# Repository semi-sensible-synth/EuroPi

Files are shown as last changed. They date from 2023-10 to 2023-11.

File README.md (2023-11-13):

# EuroPi (Semi-Sensible Synth THT KiCad remix)

This is a remix of the [original EuroPi](https://github.com/Allen-Synthesis/EuroPi) eurorack module with a few changes:

- Input jacks at bottom, above output jacks
- Uses cheaper (?) tactile buttons
- Uses a 38mm OLED, commonly sold on AliExpress

If you are building one right now ... [use the iBOM](https://rawcdn.githack.com/semi-sensible-synth/EuroPi/e1486020547788293de8dd8d0f69c1b8743ea925/hardware/EuroPi/kicad/ibom/ibom.html) to help with parts placement.

The EuroPi is a fully user reprogrammable module based on the [Raspberry Pi Pico](https://www.raspberrypi.com/products/raspberry-pi-pico/), which allows users to process inputs and controls to produce outputs based on code written in Python. The entire project is open-source.

<p>
  <a href="https://discord.gg/JaQwtCnBV5">
        chat on Discord
  </a>
  <a href="https://www.reddit.com/r/EuroPi/">
        
  </a>
  <a href="https://github.com/Allen-Synthesis/EuroPi/tree/main/software/contrib">
        
  </a>
  <a href="https://github.com/Allen-Synthesis/EuroPi/releases/">
        
  </a>
  
</p>

---

This repository relates to the EuroPi module, however some users may be expecting to see what is now referred to as the 'EuroPi Prototype'. The repository for this (now deprecated) module [can be found here](https://github.com/roryjamesallen/EuroPi-Prototype)

You can find more about this and other projects of mine on [my website](https://www.allensynthesis.co.uk)

europi-sss-tht_module_pron

## Capabilities

* 6 0-10V Control Voltage outputs, each with indicator LED
* 2 Knobs with 12 bit resolution
* 2 Push Buttons
* 1 0-12V Control Voltage input with 12 bit resolution
* 1 Digital input for external clocking or gate sources
* 128x32 OLED Display
* I²C expansion header on the rear for extra sensors or outputs

### Documentation

**Hardware**: Details of the hardware can be found at [hardware README](hardware/EuroPi/README.md). Additionally the [BoM](hardware/EuroPi/bill_of_materials.md) and the [build guide](hardware/EuroPi/build_guide.md) can be found in the hardware folder.

**Software**: Before using any of the software, follow the instructions in [programming_instructions.md](software/programming_instructions.md) to set up and calibrate your module.

A list of user contributed scripts and their usage can be found in [contrib/README.md](software/contrib/README.md).
There is also a [YouTube playlist](https://www.youtube.com/playlist?list=PLbingtr9KGPUdIODLWgzgAdIyN497YyEs) showcasing EuroPi and some of the different scripts available.

The EuroPi firmware API documentation can be found at https://allen-synthesis.github.io/EuroPi/. This documentation will explain all of the available features of the EuroPi firmware API. It also includes some examples of how to use various features of the firmware as well as [interesting_things.md](software/interesting_things.md).

If you would like to extend any of the features of the EuroPi software, you can view the firmware source code at [europi.py](software/firmware/europi.py).

### Issues
If you find any bugs, either in the software, the hardware, or the documentation, please create an Issue by clicking the 'Issue' tab along the top.  
Please feel free to create any issue you see fit, I'll either attempt to fix it or explain it.  
There are Issue templates available, so please choose whichever is most relevant, depending on if your Issue is a hardware or software bug, if it's a documentation error or suggestion, if it's a question about the project as a whole, or a suggestion about the project as a whole.

### License

This module, and any documentation included in this repository, is entirely "free" software and hardware, under different licenses depending on the software, hardware, and documentation itself.

* Software: [Apache 2.0](software/LICENSE)
* Hardware: [CERN OHL-S v2](hardware/LICENSE)
* Documentation: [CC0 1.0](LICENSE)

Anyone is welcome to design their own versions of the idea, or modify my designs.
The only thing I would ask is that you refrain from using the brand name 'Allen Synthesis' on your DIY builds if they have modified my files in any way, just to prevent any confusion if they end up being re-sold or distributed. This is in line with section 8.2 of the CERN license. You may use the brand name if you have simply copied the files from this repository to replicate without modification.
  
If you have a bug fix or improvement that you think is worth sharing, then feel free to send over any pictures or documentation and it can be merged with the main project!
 
### Disclaimer
 
Recreate any of the files found in this repository at your own risk; I will attempt to solve any issues that you might have with my designs, but I can't guarantee that there are not minor bugs in any of the documents, both hardware and software.

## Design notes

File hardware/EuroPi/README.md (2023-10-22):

# EuroPi hardware (Semi-Sensible Synth THT KiCad remix)

This version of EuroPi is a remix with some small changes.

## Differences / changes from stock EuroPi

- Input jacks at bottom, above output jacks
- Uses 14mm high, 6x6mm base tactile buttons with ~6.1-6.2mm diameter plastic caps.
- Uses a 38mm OLED, commonly sold on AliExpress (mounted slightly offset from centre for your OCD)
- Has a bodge zone with some extra holes and exposed pads for cutting traces and re-routing the OLED pins if yours doesn’t follow the ‘CPC’-style pinout (less elegant than the original EuroPi rerouting holes, but intended as a last resort if you happen to have another OLED that still fits)
- Has optional non-electrical pin header to help support the other end of the OLED
- No standoff screw joining boards, extra pin headers at bottom instead
- General re-routing and component position tweaks to make it all work.

## BOM variations of note

- 0.91” OLED (38mm wide, GND/VCC/SCL/SDA): [Ali Express](https://www.aliexpress.com/item/32672229793.html)
- 6x6x14 mm tactile buttons: [Ali Express](https://www.aliexpress.com/item/32960657626.html)
- Tactile button caps: [Ali Express (white)](https://www.aliexpress.com/item/32872180785.html), [Ali Express (black)](https://www.aliexpress.com/item/32873394381.html)

These are common parts across various sellers, so should be relatively easy to find at a good price.

## v0.10.0-sss-tht TODO notes

I have ordered and built a module using the `v0.10.0-sss-tht` production files and it works.
These are some minor changes I would make in a revision.

- Add more component value labels to silkscreen, especially to resistors
- Add + to LED silkscreen
- LED panel holes could be a little smaller (~0.4mm diameter smaller)
- Consider adding pin headers between the front panel and PCB, above the OLED to better secure when using nut-less trimmer pots.
  - _(This would be a female header above the OLED and an SMD right angle male header on exposed pads on the back of the front panel - or get fancy with a solderable standoff like https://www.adafruit.com/product/4207)_
- Build guide: 
  - Solder the I2C header before Pico & power header (tricky otherwise)
  - Solder the bottom centre jack (J5) before bottom board joiner on the opposite side of the board (if using 8x1 with two middle pins removed as joiner). If you forget, it can be soldered from the opposite side of the board.
  - I had to glue my button caps on to the tactile buttons - not a big deal, but I expected them to attach via friction
  - I used small plastic trimmer pots in my first build, however it’s better to use proper metal pots with nuts. This is because without pot nuts, pressing the buttons too hard flexes the PCB away from the front panel. Using [trimmer knobs](https://www.aliexpress.com/item/1005002336855641.html) also help.

# Hardware Specifications

## Outputs
- 1k Output Impedance
- RC filter smoothed PWM
- ~1.5kHz Maximum usable frequency (without changing RC values)
- 0.000176V Maximum ripple peak-to-peak
- 0.0108s Settle time from 0% to 90% duty cycle
- 0-10V

## Analogue Input
- 100k Input Impedance
- 0-12V Readable Range
- Protected for ±36V (TL074 limits, MCP6002 will always clip to ±3.3V)

## Digital Input
- 100k Input Impedance
- 0.8V threshold to read as high

## OLED
- SSD1306 0.91"
- 128 x 32 pixels
- I2C Protocol

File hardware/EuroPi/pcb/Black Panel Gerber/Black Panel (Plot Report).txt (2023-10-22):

Plot Report
-----------

Report Written:     Saturday, December 25, 2021
Design Path:        C:\Users\Rory\Documents\Allen Synthesis Website\Modules\EuroPi\HUGE 8HP, Screen\Hardware\PCB\Alternate Panels\Black Panel.pcb
Design Title:       
Created:            15/10/2021 18:21:02
Last Saved:         25/12/2021 14:56:07
Editing Time:       781 min
Units:              mm (precision 1)

Device Settings
===============

Gerber Settings
===============

    Leading zero suppression.
    G01 assumed throughout.
    Line termination <*> <CR> <LF>.
    3.5 format absolute mm.

    Format commands defined in Gerber file.
    Aperture table defined in Gerber file.
    Hardware arcs allowed.

Drill Settings
==============

    Excellon Format 1
    Format 3.5 absolute in mm.
    Zero suppression None

Plots Output
============

    Plot Job: "C:\Users\Rory\Documents\Allen Synthesis Website\Modules\EuroPi\HUGE 8HP, Screen\Hardware\PCB\Alternate Panels\Black Panel.mop"

Gerber Output
=============

C:\Users\Rory\Documents\Allen Synthesis Website\Modules\EuroPi\HUGE 8HP, Screen\Hardware\PCB\Alternate Panels\Black Panel Gerber\Black Panel - Bottom Silkscreen.gbr

    Layers:
    ---------------------
    Bottom Silkscreen

    D-Code Shape  (mm)
    ---------------------
    D87    Round 0.025

Gerber Output
=============

C:\Users\Rory\Documents\Allen Synthesis Website\Modules\EuroPi\HUGE 8HP, Screen\Hardware\PCB\Alternate Panels\Black Panel Gerber\Black Panel - Bottom Copper.gbr

    Layers:
    -----------------
    Bottom Copper

    D-Code Shape  (mm)
    ----------------------
    D87    Round 0.025
    D93    Round 8.000
    D140   Round 7.000
    D141   Round 10.000
    D142   Round 4.000

Gerber Output
=============

C:\Users\Rory\Documents\Allen Synthesis Website\Modules\EuroPi\HUGE 8HP, Screen\Hardware\PCB\Alternate Panels\Black Panel Gerber\Black Panel - Bottom Copper (Resist).gbr

    Layers:
    -----------------
    Bottom Copper

    D-Code Shape  (mm)
    ----------------------
    D87    Round 0.025
    D93    Round 8.000
    D140   Round 7.000
    D141   Round 10.000
    D142   Round 4.000

Gerber Output
=============

C:\Users\Rory\Documents\Allen Synthesis Website\Modules\EuroPi\HUGE 8HP, Screen\Hardware\PCB\Alternate Panels\Black Panel Gerber\Black Panel - Bottom Copper (Paste).gbr

    Layers:
    -----------------
    Bottom Copper

    D-Code Shape  (mm)
    ---------------------

NC Drill Output
===============

C:\Users\Rory\Documents\Allen Synthesis Website\Modules\EuroPi\HUGE 8HP, Screen\Hardware\PCB\Alternate Panels\Black Panel Gerber\Black Panel - Drill Data - [Through Hole].drl

    Output:
    ---------------------------
    Plated Round Drill Holes
    Plated Slots

    Tool  Size       Count   ID
    ----------------------------------
    T001  3.10000 mm 6     I
    T002  3.20000 mm 2     H
    T003  6.10000 mm 8     F
    T004  7.10000 mm 2     K
    T005  9.10000 mm 2     G
    ----------------------------------
    Total            20
    ----------------------------------

C:\Users\Rory\Documents\Allen Synthesis Website\Modules\EuroPi\HUGE 8HP, Screen\Hardware\PCB\Alternate Panels\Black Panel Gerber\Black Panel - Drill Data - [Through Hole] (Unplated).drl

    Output:
    -----------------------------
    Unplated Round Drill Holes
    Unplated Slots

    Tool  Size Count   ID
    ----------------------------
    ----------------------------
    Total      0
    ----------------------------

Gerber Output
=============

C:\Users\Rory\Documents\Allen Synthesis Website\Modules\EuroPi\HUGE 8HP, Screen\Hardware\PCB\Alternate Panels\Black Panel Gerber\Black Panel - Outline.gbr

    Layers:
    ------------------
    Board Outlines

    D-Code Shape  (mm)
    ---------------------
    D13    Round 0.305

End Of Report.

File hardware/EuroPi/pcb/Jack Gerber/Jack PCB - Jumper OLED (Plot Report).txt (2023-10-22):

Plot Report
-----------

Report Written:     Monday, December 20, 2021
Design Path:        C:\Users\Rory\Documents\Allen Synthesis Website\Modules\EuroPi\HUGE 8HP, Screen\Hardware\PCB\Jack PCB - Jumper OLED.pcb
Design Title:       
Created:            09/09/2021 13:46:40
Last Saved:         20/12/2021 13:36:13
Editing Time:       1605 min
Units:              mm (precision 1)

Device Settings
===============

Gerber Settings
===============

    Leading zero suppression.
    G01 assumed throughout.
    Line termination <*> <CR> <LF>.
    3.5 format absolute mm.

    Format commands defined in Gerber file.
    Aperture table defined in Gerber file.
    Hardware arcs allowed.

Drill Settings
==============

    Excellon Format 1
    Format 3.5 absolute in mm.
    Zero suppression None

Plots Output
============

    Plot Job: "C:\Users\Rory\Documents\Allen Synthesis Website\Modules\EuroPi\HUGE 8HP, Screen\Hardware\PCB\Jack PCB - Jumper OLED.mop"

Gerber Output
=============

C:\Users\Rory\Documents\Allen Synthesis Website\Modules\EuroPi\HUGE 8HP, Screen\Hardware\PCB\Jack Gerber\Jack PCB - Jumper OLED - Top Copper.gbr

    Layers:
    --------------
    Top Copper

    D-Code Shape  (mm)
    ----------------------
    D13    Round 0.305
    D14    Round 0.254
    D15    Round 0.500
    D17    Round 1.600
    D18    Round 1.524
    D19    Round 2.000
    D29    Round 2.500
    D72    Square 2.500
    D73    Round 3.500
    D75    Round 1.500
    D129   Round 3.200
    D137   Round 1.800

Gerber Output
=============

C:\Users\Rory\Documents\Allen Synthesis Website\Modules\EuroPi\HUGE 8HP, Screen\Hardware\PCB\Jack Gerber\Jack PCB - Jumper OLED - Top Copper (Resist).gbr

    Layers:
    --------------
    Top Copper

    D-Code Shape  (mm)
    ----------------------
    D71    Round 1.778
    D20    Round 2.254
    D77    Round 2.754
    D78    Square 2.754
    D79    Round 3.754
    D81    Round 1.754
    D130   Round 3.454
    D138   Round 2.054

Gerber Output
=============

C:\Users\Rory\Documents\Allen Synthesis Website\Modules\EuroPi\HUGE 8HP, Screen\Hardware\PCB\Jack Gerber\Jack PCB - Jumper OLED - Top Copper (Paste).gbr

    Layers:
    --------------
    Top Copper

    D-Code Shape  (mm)
    ---------------------

Gerber Output
=============

C:\Users\Rory\Documents\Allen Synthesis Website\Modules\EuroPi\HUGE 8HP, Screen\Hardware\PCB\Jack Gerber\Jack PCB - Jumper OLED - Top Silkscreen.gbr

    Layers:
    ------------------
    Top Silkscreen

    D-Code Shape  (mm)
    ---------------------
    D10    Round 0.127
    D13    Round 0.305
    D137   Round 1.800
    D139   Round 0.150

Gerber Output
=============

C:\Users\Rory\Documents\Allen Synthesis Website\Modules\EuroPi\HUGE 8HP, Screen\Hardware\PCB\Jack Gerber\Jack PCB - Jumper OLED - Bottom Copper.gbr

    Layers:
    -----------------
    Bottom Copper

    D-Code Shape  (mm)
    ---------------------
    D15    Round 0.500
    D17    Round 1.600
    D18    Round 1.524
    D19    Round 2.000
    D129   Round 3.200
    D137   Round 1.800

Gerber Output
=============

C:\Users\Rory\Documents\Allen Synthesis Website\Modules\EuroPi\HUGE 8HP, Screen\Hardware\PCB\Jack Gerber\Jack PCB - Jumper OLED - Bottom Copper (Resist).gbr

    Layers:
    -----------------
    Bottom Copper

    D-Code Shape  (mm)
    ---------------------
    D71    Round 1.778
    D20    Round 2.254
    D130   Round 3.454
    D138   Round 2.054

Gerber Output
=============

C:\Users\Rory\Documents\Allen Synthesis Website\Modules\EuroPi\HUGE 8HP, Screen\Hardware\PCB\Jack Gerber\Jack PCB - Jumper OLED - Bottom Copper (Paste).gbr

    Layers:
    -----------------
    Bottom Copper

    D-Code Shape  (mm)
    ---------------------

Gerber Output
=============

C:\Users\Rory\Documents\Allen Synthesis Website\Modules\EuroPi\HUGE 8HP, Screen\Hardware\PCB\Jack Gerber\Jack PCB - Jumper OLED - Bottom Silkscreen.gbr

    Layers:
    ---------------------
    Bottom Silkscreen

    D-Code Shape  (mm)
    ---------------------
    D10    Round 0.127
    D11    Round 0.100
    D13    Round 0.305

NC Drill Output
===============

C:\Users\Rory\Documents\Allen Synthesis Website\Modules\EuroPi\HUGE 8HP, Screen\Hardware\PCB\Jack Gerber\Jack PCB - Jumper OLED - Drill Data - [Through Hole].drl

    Output:
    ---------------------------
    Plated Round Drill Holes
    Plated Slots

    Tool  Size       Count   ID
    ----------------------------------
    T001  0.60000 mm 12    M
    T002  0.80000 mm 57    W
    T003  0.88900 mm 4     O
    T004  1.00000 mm 56    A
    T005  1.10000 mm 14    C
    T006  1.50000 mm 24    R
    T007  3.00000 mm 5     D
    ----------------------------------
    Total            172
    ----------------------------------

C:\Users\Rory\Documents\Allen Synthesis Website\Modules\EuroPi\HUGE 8HP, Screen\Hardware\PCB\Jack Gerber\Jack PCB - Jumper OLED - Drill Data - [Through Hole] (Unplated).drl

    Output:
    -----------------------------
    Unplated Round Drill Holes
    Unplated Slots

    Tool  Size Count   ID
    ----------------------------
    ----------------------------
    Total      0
    ----------------------------

Gerber Output
=============

C:\Users\Rory\Documents\Allen Synthesis Website\Modules\EuroPi\HUGE 8HP, Screen\Hardware\PCB\Jack Gerber\Jack PCB - Jumper OLED - Drill Ident Drawing - [Through Hole].gbr

    Layers:
    ------------------
    [Through Hole]

Drill Ident Drawing
===================

    Drill Plated Size  Shape ID
    ------------------------------------
    1.000 Y      2.540 Round A
    1.100 Y      2.540 Round C
    3.000 Y      2.540 Round D
    0.600 Y      2.540 Round M
    0.889 Y      2.540 Round O
    1.500 Y      2.540 Round R
    0.800 Y      2.540 Round W

    D-Code Shape  (mm)
    ---------------------
    D10    Round 0.127
    D12    Round 2.540

Gerber Output
=============

C:\Users\Rory\Documents\Allen Synthesis Website\Modules\EuroPi\HUGE 8HP, Screen\Hardware\PCB\Jack Gerber\Jack PCB - Jumper OLED - Outline.gbr

    Layers:
    ------------------
    Board Outlines

    D-Code Shape  (mm)
    ---------------------
    D13    Round 0.305

End Of Report.

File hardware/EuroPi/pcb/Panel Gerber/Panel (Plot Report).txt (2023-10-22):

Plot Report
-----------

Report Written:     Thursday, December 16, 2021
Design Path:        C:\Users\Rory\Documents\Allen Synthesis Website\Modules\EuroPi\HUGE 8HP, Screen\Hardware\PCB\Panel.pcb
Design Title:       
Created:            15/10/2021 18:21:02
Last Saved:         16/12/2021 18:22:28
Editing Time:       334 min
Units:              mm (precision 1)

Device Settings
===============

Gerber Settings
===============

    Leading zero suppression.
    G01 assumed throughout.
    Line termination <*> <CR> <LF>.
    3.5 format absolute mm.

    Format commands defined in Gerber file.
    Aperture table defined in Gerber file.
    Hardware arcs allowed.

Drill Settings
==============

    Excellon Format 1
    Format 3.5 absolute in mm.
    Zero suppression None

Plots Output
============

Gerber Output
=============

C:\Users\Rory\Documents\Allen Synthesis Website\Modules\EuroPi\HUGE 8HP, Screen\Hardware\PCB\Panel Gerber\Panel - Top Copper.gbr

    Layers:
    --------------
    Top Copper

    D-Code Shape  (mm)
    ----------------------
    D93    Round 8.000
    D140   Round 7.000
    D141   Round 10.000
    D142   Round 4.000

Gerber Output
=============

C:\Users\Rory\Documents\Allen Synthesis Website\Modules\EuroPi\HUGE 8HP, Screen\Hardware\PCB\Panel Gerber\Panel - Bottom Silkscreen.gbr

    Layers:
    ---------------------
    Bottom Silkscreen

    D-Code Shape  (mm)
    ---------------------
    D87    Round 0.025

Gerber Output
=============

C:\Users\Rory\Documents\Allen Synthesis Website\Modules\EuroPi\HUGE 8HP, Screen\Hardware\PCB\Panel Gerber\Panel - Bottom Copper (Resist).gbr

    Layers:
    -----------------
    Bottom Copper

    D-Code Shape  (mm)
    ---------------------

Gerber Output
=============

C:\Users\Rory\Documents\Allen Synthesis Website\Modules\EuroPi\HUGE 8HP, Screen\Hardware\PCB\Panel Gerber\Panel - Bottom Copper (Paste).gbr

    Layers:
    -----------------
    Bottom Copper

    D-Code Shape  (mm)
    ---------------------

NC Drill Output
===============

C:\Users\Rory\Documents\Allen Synthesis Website\Modules\EuroPi\HUGE 8HP, Screen\Hardware\PCB\Panel Gerber\Panel - Drill Data - [Through Hole].drl

    Output:
    ---------------------------
    Plated Round Drill Holes
    Plated Slots

    Tool  Size       Count   ID
    ----------------------------------
    T001  3.10000 mm 6     I
    T002  3.20000 mm 2     H
    T003  6.10000 mm 8     F
    T004  7.10000 mm 2     K
    T005  9.10000 mm 2     G
    ----------------------------------
    Total            20
    ----------------------------------

C:\Users\Rory\Documents\Allen Synthesis Website\Modules\EuroPi\HUGE 8HP, Screen\Hardware\PCB\Panel Gerber\Panel - Drill Data - [Through Hole] (Unplated).drl

    Output:
    -----------------------------
    Unplated Round Drill Holes
    Unplated Slots

    Tool  Size Count   ID
    ----------------------------
    ----------------------------
    Total      0
    ----------------------------

Gerber Output
=============

C:\Users\Rory\Documents\Allen Synthesis Website\Modules\EuroPi\HUGE 8HP, Screen\Hardware\PCB\Panel Gerber\Panel - Outline.gbr

    Layers:
    ------------------
    Board Outlines

    D-Code Shape  (mm)
    ---------------------
    D13    Round 0.305

End Of Report.

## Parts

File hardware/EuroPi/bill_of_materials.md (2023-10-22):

# Bill of Materials

In addition to the Front Panel, Jack PCB, and Pico PCB (bought from Allen Synthesis or a third-party supplier), you will need the following components to complete your build.
You will also need one 3.5mm cable (normal Eurorack patch cable) to perform the calibration process.  
  
Please note that a few of these are multi-packs of components, and there may well be cheaper alternatives if you are doing a single build, so as long as the specification is the same you can get any of these components from any supplier most accessible to you.

| Component | Quantity | Value | Description | Suggested Supplier
|-|-|-|-|-|
| R1 - R12, R19 - R20 | 14 | 1k | 1 Kiloohm Resistor | [CPC](https://cpc.farnell.com/unbranded/mf25-1k/resistor-0-25w-1-1k/dp/RE03722)
|R13 - R18 | 6 | 4.7k | 4.7 Kiloohm Resistor | [CPC](https://cpc.farnell.com/unbranded/mf25-4k7/resistor-0-25w-1-4k7/dp/RE03757)
| R21 - R23 | 3 | 22k | 22 Kiloohm Resistor | [CPC](https://cpc.farnell.com/unbranded/mf25-22k/resistor-0-25w-1-22k/dp/RE03743)
| R24 - R26 | 3 | 10k | 10 Kiloohm Resistor | [CPC](https://cpc.farnell.com/unbranded/mf25-10k/resistor-0-25w-1-10k/dp/RE03723)
| R27 - R34 | 8 | 100k | 100 Kiloohm Resistor | [CPC](https://cpc.farnell.com/unbranded/mf25-100k/resistor-0-25w-1-100k/dp/RE03724)
| R35 - R40 | 6 | 220k | 220 Kiloohm Resistor | [CPC](https://cpc.farnell.com/unbranded/mf25-220k/resistor-0-25w-1-220k/dp/RE03744)
| C1 - C2 | 2 | 1uF | 1 Microfarad Capacitor (Polarised)| [CPC](https://cpc.farnell.com/multicomp/mcmhr50v105m4x7/capacitor-1uf-50v-radial-105-deg/dp/CA08237)
| C3 - C14 | 12 | 100nF | 100 Nanofarad Capacitor (Non-Polarised)| [CPC](https://cpc.farnell.com/multicomp/mcrr50104x7rk0050/capacitor-100nf-50v/dp/CA06296)
| C15 - C16 | 2 | 10uF | 10 Microfarad Capacitor (Polarised)| [CPC](https://cpc.farnell.com/panasonic/eeueb1j100s/capacitor-10uf-63v-5x11mm/dp/CA08350)
| D1 - D4 | 4 | 1N5817 | Schottky Diode | [CPC](https://cpc.farnell.com/multicomp-pro/1n5817/schottky-rectifier-1a-20v-do-204al/dp/SC15528)
| LED1 - LED6 | 6 | L-424HDT | 3mm LED | [CPC](https://cpc.farnell.com/kingbright/l-424hdt/led-flat-top-3mm-red/dp/SC11541)
| VR1 - VR2 | 2 | 10k | 10 Kiloohm Linear Rotary Potentiometer | [CPC](https://cpc.farnell.com/alps/rk09k11310kb/potentiometer-10k-lin/dp/RE04560), [Thonk](https://www.thonk.co.uk/shop/alpha-9mm-pots-vertical-t18/) (B10K - T18 Shaft - Alpha Vertical Potentiometer)
| SW1 - SW2 | 2 | 6x6 tactile button | 6x6 14mm high momentary tactile button | [Ali Express](https://www.aliexpress.com/item/32960657626.html)
| | 2 | G63 6mm button cap | Tactile button cap | [Ali Express (white)](https://www.aliexpress.com/item/32872180785.html), [Ali Express (black)](https://www.aliexpress.com/item/32873394381.html)
| OLED1 | 1 | 0.91" SSD1306 | I2C OLED Display (38 mm wide) | [Ali Express](https://www.aliexpress.com/item/32672229793.html)
| J1 - J8 | 8 | PJ398SM | Thonkiconn 3.5mm Mono Jack | [Thonk](https://www.thonk.co.uk/shop/thonkiconn/), [Banananuts](https://www.thonk.co.uk/shop/bananuts/), [Cosmonuts](https://www.thonk.co.uk/shop/cosmonuts/)
| CONN0 | 2 (pairs) | 20x1 2.54mm | Pico Connection Header (Male + Female) | [Male](https://cpc.farnell.com/harwin/m22-2012005/header-vertical-1row-20way/dp/CN14644), [Female](https://cpc.farnell.com/multicomp/2212s-20sg-85/socket-pcb-1-row-20way/dp/CN14539)
| CONN1 - CONN4 | 2 (pairs) | 4x2 2.54mm | PCB Connection Header (Male + Female) | [Male](https://cpc.farnell.com/harwin/m20-9980445/header-2row-4way/dp/CN14381), [Female](https://cpc.farnell.com/multicomp/2214s-08sg-85/socket-pcb-2-54mm-2-row-vert-8way/dp/CN18449)
| CONN5 | 1 | 4x1 2.54mm | I2C Header (Male) | [CPC](https://cpc.farnell.com/multicomp/2211s-04g/header-1-row-vert-4way/dp/CN14489)
| CONN6 | 1 | 5x2 2.54mm | Eurorack Power Header (Shrouded) | [CPC](https://cpc.farnell.com/3m/n2510-6002rb/2-54mm-header-straight-10-way/dp/CN20355)
| TL074-1 - TL074-2 | 2 | TL074 DIP | Quad Operational Amplifier (+ Socket) | [Op-Amp](https://cpc.farnell.com/texas-instruments/tl074acn/ic-op-amp-quad-jfet-dip14/dp/SC16602), [Socket](https://cpc.farnell.com/unbranded/mc-2227-14-03-f1/socket-ic-dil-0-3-tube-34-14way/dp/SC08125)
| MCP6002 | 1 | MCP6002 DIP | Dual Operational Amplifier (+ Socket) | [Op-Amp](https://cpc.farnell.com/microchip/mcp6002-i-p/ic-op-amp-1-8v-1mhz-dual-pdip8/dp/SC17118), [Socket](https://cpc.farnell.com/multicomp/spc15494/dip-socket-8pos-2row-2-54mm-th/dp/SC15358)
| Q1 | 1 | 2N3904 | NPN Transistor | [CPC](https://cpc.farnell.com/multicomp-pro/2n3904/transistor-npn-to-92/dp/SC15978)
| 7805 | 1 | L7805ABV | 5V Linear Voltage Regulator | [CPC](https://cpc.farnell.com/stmicroelectronics/l7805abv/ic-v-reg-5v/dp/SC10586)
| | 1 | 11mm | M2.5 PCB Standoff + 2 Screws | [Standoff](https://cpc.farnell.com/ettinger/05-02-113/spacer-hex-m2-5-11mm-length-brass/dp/PC01763), [Screws](https://cpc.farnell.com/unbranded/pp2m5-6/screw-pan-pozi-m2-5-x-6mm-100pk/dp/FN02140)
| | 2 | T18 Shaft | Knobs | [Thonk](https://www.thonk.co.uk/shop/1900h-t18/) NOTE: If you buy D-Shaft potentiometers, the knobs must be 'Reverse-D-Shaft' type.
| | 1 | 10 - 16 Pin | Eurorack Power Cable | [Thonk](https://www.thonk.co.uk/shop/eurorack-power-cables/)
| | 1 | | Micro USB Cable (Capable of Data Transfer) | [CPC](https://cpc.farnell.com/pro-signal/psg91562/lead-usb-a-male-micro-b-male-black/dp/CS32732), [The Pi Hut](https://thepihut.com/products/usb-to-micro-usb-cable-0-5m)
| | 1 | | Raspberry Pi Pico | [The Pi Hut](https://thepihut.com/products/raspberry-pi-pico), [CPC](https://cpc.farnell.com/raspberry-pi/raspberry-pi-pico/raspberry-pi-pico-rp2040-mcu-board/dp/SC17106)

#### Note about OLED

The OLED is a different model to the original EuroPi design. This version expects 38mm wide 0.91" OLEDs (common on Ali Express), albeit slightly offset from center. The default pin configuration is correct for the OLED in the BOM (GND/VCC/SCL/SDA), however the module supports alternative pin configurations via a some exposed pads in 'bodge' area. You can connect these as required if you happen to have a different pinout. 

38mm_OLED_dimensions

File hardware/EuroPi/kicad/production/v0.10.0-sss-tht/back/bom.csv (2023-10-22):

Designator | Footprint | Quantity | Value | LCSC Part #
C1, C2 | CP_Radial_D5.0mm_P2.50mm | 2 | 1uF
C10, C11, C12, C13, C14, C3, C4, C5, C6, C9 | Capacitor Small Non-Polarised | 10 | 100nF
C15, C16 | CP_Radial_D8.0mm_P3.80mm | 2 | 10uF
CONN1, CONN3 | PinHeader_2x04_P2.54mm_Vertical | 2 | Conn_02x04_Counter_Clockwise_M
CONN5 | PinHeader_1x04_P2.54mm_Vertical | 1 | Conn_01x04_Male
CONN6, CONN7 | PinHeader_1x03_P2.54mm_Vertical | 2 | Conn_02x03_M
D1, D2, D3, D4 | Schottky Diode | 4 | type="D" model="DIODE" lib=""
EuroPower1 | Eurorack Power Header Unlabeled | 1 | Eurorack Power
IC1, IC2 | DIP-14 IC Socket | 2 | TL074
IC3 | DIP-8 IC Socket | 1 | MCP6002
Q1 | TO-92 | 1 | 2N2222
R1, R2, R3, R4, R5, R6 | R_Axial_DIN0204_L3.6mm_D1.6mm_P7.62mm_Horizontal | 6 | 1K
R21, R22, R23 | R_Axial_DIN0204_L3.6mm_D1.6mm_P7.62mm_Horizontal | 3 | 22K
R24, R25, R26 | R_Axial_DIN0204_L3.6mm_D1.6mm_P7.62mm_Horizontal | 3 | 10K
R27, R28, R29, R30, R31, R32, R33, R34 | R_Axial_DIN0204_L3.6mm_D1.6mm_P7.62mm_Horizontal | 8 | 100K
R35, R36, R37, R38, R39, R40 | R_Axial_DIN0204_L3.6mm_D1.6mm_P7.62mm_Horizontal | 6 | 220K
REG1 | TO-220-3_Vertical | 1 | L7805
RPI1 | Raspberry Pi Pico | 1 | Raspberry_Pi_Pico

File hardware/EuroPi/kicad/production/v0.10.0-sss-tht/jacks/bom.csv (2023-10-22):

Designator | Footprint | Quantity | Value | LCSC Part #
C7, C8 | Capacitor Small Non-Polarised | 2 | 100nF
CONN10, CONN8, CONN9 | PinSocket_1x03_P2.54mm_Vertical | 3 | Conn_02x03_F
CONN11 | PinHeader_1x04_P2.54mm_Vertical | 1 | Conn_01x04_Counter_Clockwise_M
CONN2, CONN4 | PinSocket_2x04_P2.54mm_Vertical | 2 | Conn_02x04_Counter_Clockwise_F
J1, J2, J3, J4, J5, J6, J7, J8 | Thonkiconn Mono Jack | 8 | Thonkiconn_Mono_Jack
JP1, JP2, JP3, JP4 | SolderJumper-2_P1.3mm_Bridged_Pad1.0x1.5mm | 4 | SolderJumper_2_Bridged
LED1, LED2, LED3, LED4, LED5, LED6 | LED 3mm | 6 | LED
OLED1 | OLED SSD1306 0.91-38mm | 1 | OLED SSD1306_0.91"
R10, R11, R12, R19, R20, R7, R8, R9 | R_Axial_DIN0204_L3.6mm_D1.6mm_P7.62mm_Horizontal | 8 | 1K
R13, R14, R15, R16, R17, R18 | R_Axial_DIN0204_L3.6mm_D1.6mm_P7.62mm_Horizontal | 6 | 4K7
SW1, SW2 | SW_PUSH_6mm | 2 | SW_Push
VR1 | Potentiometer_RV09 | 1 | KNOB 1
VR2 | Potentiometer_RV09 | 1 | KNOB 2

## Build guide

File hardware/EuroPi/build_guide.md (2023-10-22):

# Build Guide

> **NOTE:** _This build guide hasn't been updated for the "Semi-Sensible Synth THT KiCad remix" version, however most parts are very similar. Follow the [iBOM](kicad/ibom/ibom.html)_

----

#### Introduction
This document will go through the assembly of the EuroPi module.  
If you have bought only a Panel + PCB kit, you will need to also buy all of the components found in the [bill of materials](/hardware/EuroPi/bill_of_materials.md).  
  
This build is entirely through-hole (not even any pre-soldered SMD components!) so don't worry if you're fairly new to DIY, these instructions should be all you need to make your module.  
  
This guide should explain every step in enough detail, but there are some things left out for simplicity's sake, such as the fact that after each step any long legs will need to be snipped using your wire snips or scissors. This is only necessary for components with long legs, so resistors, capacitors, and LEDs. You don't need to snip anything off any of the headers, the 7805, the jacks, potentiometers, or IC sockets.  
 
#### Skiff Friendly Build 
There are two options for some of the build, one of which makes the module more skiff friendly (37mm deep as opposed to 45mm). If you wish to make the thinner version, simply click the links that say [Skiff Friendly Option](), and follow the instructions to guide you back into the normal build at the right points. Simply ignore these links if you don't mind the module being slightly deeper.

1 all
  
## Required tools
- Soldering Iron + Solder
- Wire Snips / Scissors
- Multimeter (Very nice to have but non-essential)

2 tools

## Preparation

#### If not already soldered, solder the headers to the Pico so that they are on the opposite side to the black integrated chips. It may help to push it into a breadboard to make sure the headers are straight
_DSC2386

## Pico PCB

The 'Pico PCB' is the PCB with the outline of the Pico on it.  
The 'front' of the Pico PCB is the side with the actual Raspberry Pi Pico on it, and the 'back' is the side with the transistor outline on it.

|Front|Back|
|-----|----|
|||

#### Required Components for Pico PCB
|Component|Quantity|
|---|---|
|1k Resistor|6|
|22k Resistor|3|
|100k Resistor|8|
|220k Resistor|6|
|10k Resistor|3|
|Schottky Diode|4|
|100nF Capacitor|10|
|14 Pin IC Socket|2|
|8 Pin IC Socket|1|
|NPN Transistor|1|
|1uF Capacitor|2|
|4x2 Female Header|2|
|Shrouded Power Header|1|
|4x1 Male Header|1|
|20x1 Female Pico Header|2|
|10uF Capacitor|2|

---

### Resistors

#### Solder the 1k resistors to the front (R1, R2, R3, R4, R5, R6)
_DSC2333
_DSC2335

#### Solder the 22k resistors to the front (R21, R22, R23)
_DSC2338

#### Solder the 100k resistors to the front (R28, R29, R30, R31, R32, R33, R34)
_DSC2339

#### Solder the 220k resistors to the front (R35, R36, R37, R38, R39, R40)
_DSC2340

#### Solder the 10k resistors to the back (R24, R25, R26)
_DSC2341

#### Solder the 100k resistor to the back (R27)
_DSC2342

---

### Diodes

#### Solder the Schottky diodes to the front (D2, D3, D4), taking care of the polarity
_DSC2343

#### Solder the Schottky diode to the back (D1), taking care of the polarity
_DSC2344

---

### Small Capacitors

#### Solder the 100nF capacitors to the front (C3, C4, C5, C6, C9, C10, C11, C12, C13, C14)
_DSC2345

---

### IC Sockets

#### Solder the 14 Pin IC sockets to the front (TL072-1, TL072-2), lining up the notch with the white square on the PCB
_DSC2346

#### Solder the 8 pin IC socket to the front (MCP6002), lining up the notch with the white square on the PCB
_DSC2347

---

### Transistor

#### Solder the NPN transistor to the back (Q1), lining up the flat edge with the line on the PCB
_DSC2348

---

### Medium Capacitors

#### Solder the 1uF capacitors to the front (C1, C2), taking care of the polarity. The white stripe on the capacitor lines up with the stripe on the PCB
_DSC2349

---

### Headers

#### Solder the female headers to the back
_DSC2350

#### Solder the shrouded power header to the front
_DSC2351

#### Solder the I²C header to the front
_DSC2352

[Skiff Friendly Option](skiff_friendly_instructions.md#step-1)

#### Push the female Pico headers onto the Pico itself
_DSC2355

#### Press this new assembly onto the footprint on the PCB
_DSC2356

#### Solder the female headers from the back
_DSC2357

#### Remove the Pico from the female headers
_DSC2358
_DSC2359

---

### Large Capacitors

#### Solder the 10uF capacitors to the front (C15, C16), taking care of the polarity. The white stripe on the capacitor lines up with the stripe on the PCB
_DSC2360

---

### 7805

[Skiff Friendly Option](skiff_friendly_instructions.md#step-2)

#### Solder the 7805 power regulator to the front, with the metal side in line with the white stripe on the PCB
  
_DSC2361

---

## Jack PCB

The 'Jack PCB' is the remaining board, with the outlines for the front panel components.  
The 'front' of the Jack PCB is the side with the OLED, jack, and button outlines, and the 'back' is the side with the OLED configuration diagram.

|Front|Back|
|-----|----|
|||

---

### Resistors

#### Solder the 1k resistors to the back (R7, R8, R9, R10, R11, R12, R19, R20)
_DSC2362 5

---

#### Solder the 4.7k resistors to the back (R13, R14, R15, R16, R17, R18)
_DSC2362

---

### Small Capacitors

#### Solder the 100nF capacitors to the back (C7, C8). If your board has a polarity marking, ignore it unless you are deliberately using larger polarised capacitors than the BOM calls for, in which case make sure they line up with the PCB marking
_DSC2363

---

### Headers

#### Push the male headers into the female headers that you soldered to the Pico PCB
_DSC2364

#### Push the Jack PCB onto the other side of the male headers
_DSC2365

#### Solder the male headers to the Jack PCB
_DSC2366

#### Pull the two PCBs apart carefully to reveal the perfectly aligned male headers on the Jack PCB
_DSC2367

---

#### OLED Configuration
There are two pin configurations that the OLED used in this build commonly comes in, which are labelled on the board 'TPH' (The Pi Hut), and 'CPC' (CPC, AliExpress, most other suppliers).  
The Pi Hut display is preferable as it does not have pre-soldered headers, so is easier to mount on the board. However the CPC display is still entirely usable.  
  
This configuration setup allows you to tell the module which display you are using, as their pins are ordered differently:  
TPH: VCC, GND, SDA, SCL  
CPC: SDA, SCL, VCC, GND
  
Don't ask my why there is still not a standard for I²C pin layout in the year 2021, but here we are, and here is how to tell the module which layout you are using:
  
#### Snip some resistor legs and bend them over the end of something small and round, such as needle-nose pliers
_DSC2410

#### Push the snipped legs into the holes on the PCB according to the diagram and which OLED you have, and then solder either from the top or the bottom
_DSC2411

---

### Front Panel Components

#### Solder the push buttons to the front (SW1, SW2)
_DSC2370

#### Solder the OLED Display to the front
This is quite an awkward operation as the distance the headers need to occupy is not standard to the lengths that 2.54mm headers come in. If you are using a CPC display, your headers are probably pre-soldered, in which case you need to prop the display up somehow while you solder one pin, then go on to solder the rest once you're sure it's straight.
  
If your display is CPC, the pins will be flush with the PCB if it's at the correct height, which is difficult but possible to solder.  
  
If your display is TPH, you can either solder pins and do it the same way as the CPC method, or use extra-long pin headers instead which will make the soldering process easier, as they will protrude far enough to get a better solder joint.

_DSC2375

#### Place the potentiometers (VR1, VR2) onto the front but don't solder yet
_DSC2376

#### Place the jacks (J1, J2, J3, J4, J5, J6, J7, J8) onto the front but don't solder yet
_DSC2377

#### Place the LEDs (LED1, LED2, LED3, LED4, LED5, LED6) onto the front but don't solder yet, lining up the short leg with the white stripe on the PCB
_DSC2378

#### Push the front panel onto the components, lining up the LEDs so they are flush
_DSC2379

#### Place an elastic band or hair bobble around the PCB and panel to hold them together. I used the plastic coated wire that came with my USB cable
_DSC2380

#### Solder all the components from the back. For the potentiometers, only solder the large lugs on the sides if yours are trimmer type potentiometers. Do not solder the lugs if the potentiometers came with nuts.
_DSC2381

---

## Finish off the assembly

#### Screw the PCB standoff onto the Jack PCB so that the standoff is on the back and the screw on the front
_DSC2383

#### Push the two PCBs together, keeping them both straight to avoid bending the header pins
_DSC2384

#### Screw the second screw into the PCB standoff through front of the Pico PCB to hold the two PCBs together firmly
Don't over-tighten so hard that you damage the PCB, but you also don't want this to rattle loose so make sure it is secure.
_DSC2385

#### Push the Pico into its slot on the Pico PCB
_DSC2387

#### If not done already, peel the protective film off the OLED display
_DSC2389

#### Screw all of the nuts on to hold the components to the front panel. 
If your potentiometer came with nuts, use them, otherwise just screw on the jacks.
Also pop on the knobs.
_DSC2390

#### Finally, pop the TL074 and MCP6002 Op-Amps into their respective sockets, making sure the notch in the IC matches the notch on the socket
_DSC2391

---

### (Optional) Multimeter Tests
Use your multimeter set to continuity mode for these tests.

#### Check that there is no continuity between +12V and -12V, between +12V and Ground, and between -12V and Ground on the power header
_DSC2395

If there is continuity on any checks where there shouldn't be then make sure your solder joints are good and that there is no dirt or stray solder bridging any connections. Also make sure that your diodes and power cable are all the correct orientation.

---

### Smoke Test

#### Connect your module to your Eurorack power supply without any other modules connected
_DSC2396

Make sure the cable is connected so that the 'key' on the cable slots into the notch on the header, and the red stripe is on the bottom side of the module.
Turn on your power supply and check for any smoke or discolouration of the PCB around the power connector, and immediately unplug if either occur.  
If all is groovy, the congratulations, you've finished building your EuroPi!

---

## Admire your handiwork!

_DSC2397

#### If you have any issues with the build process or programming that are not covered in the [troubleshooting guide](/troubleshooting.md) then please drop us an email at [contact@allensynthesis.co.uk](mailto:contact@allensynthesis.com)

#### Share photos of your build with us on [Instagram](https://www.instagram.com/allensynthesis/), or [email us](mailto:contact@allensynthesis.com)!

#### Now just follow the [programming instructions](/software/programming_instructions.md) to get ready to use your new EuroPi!

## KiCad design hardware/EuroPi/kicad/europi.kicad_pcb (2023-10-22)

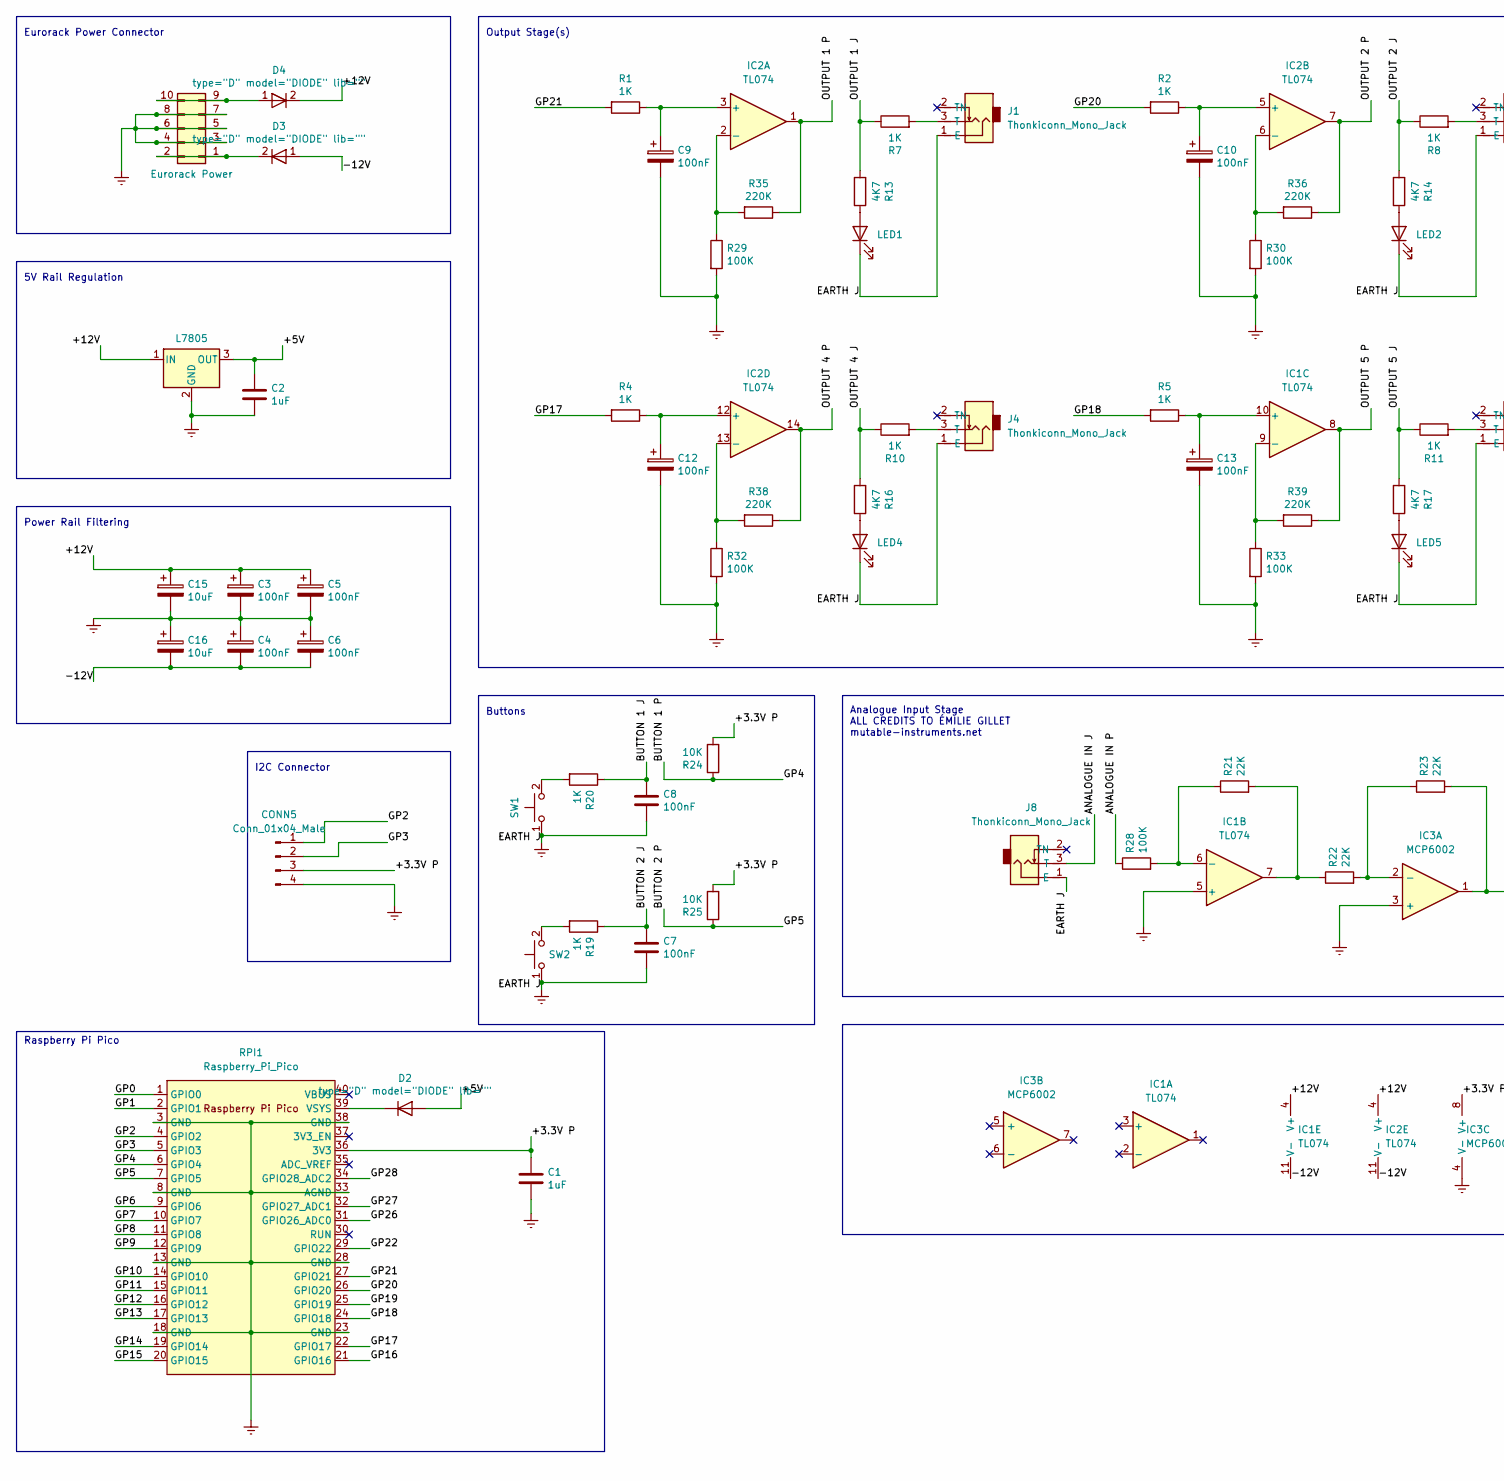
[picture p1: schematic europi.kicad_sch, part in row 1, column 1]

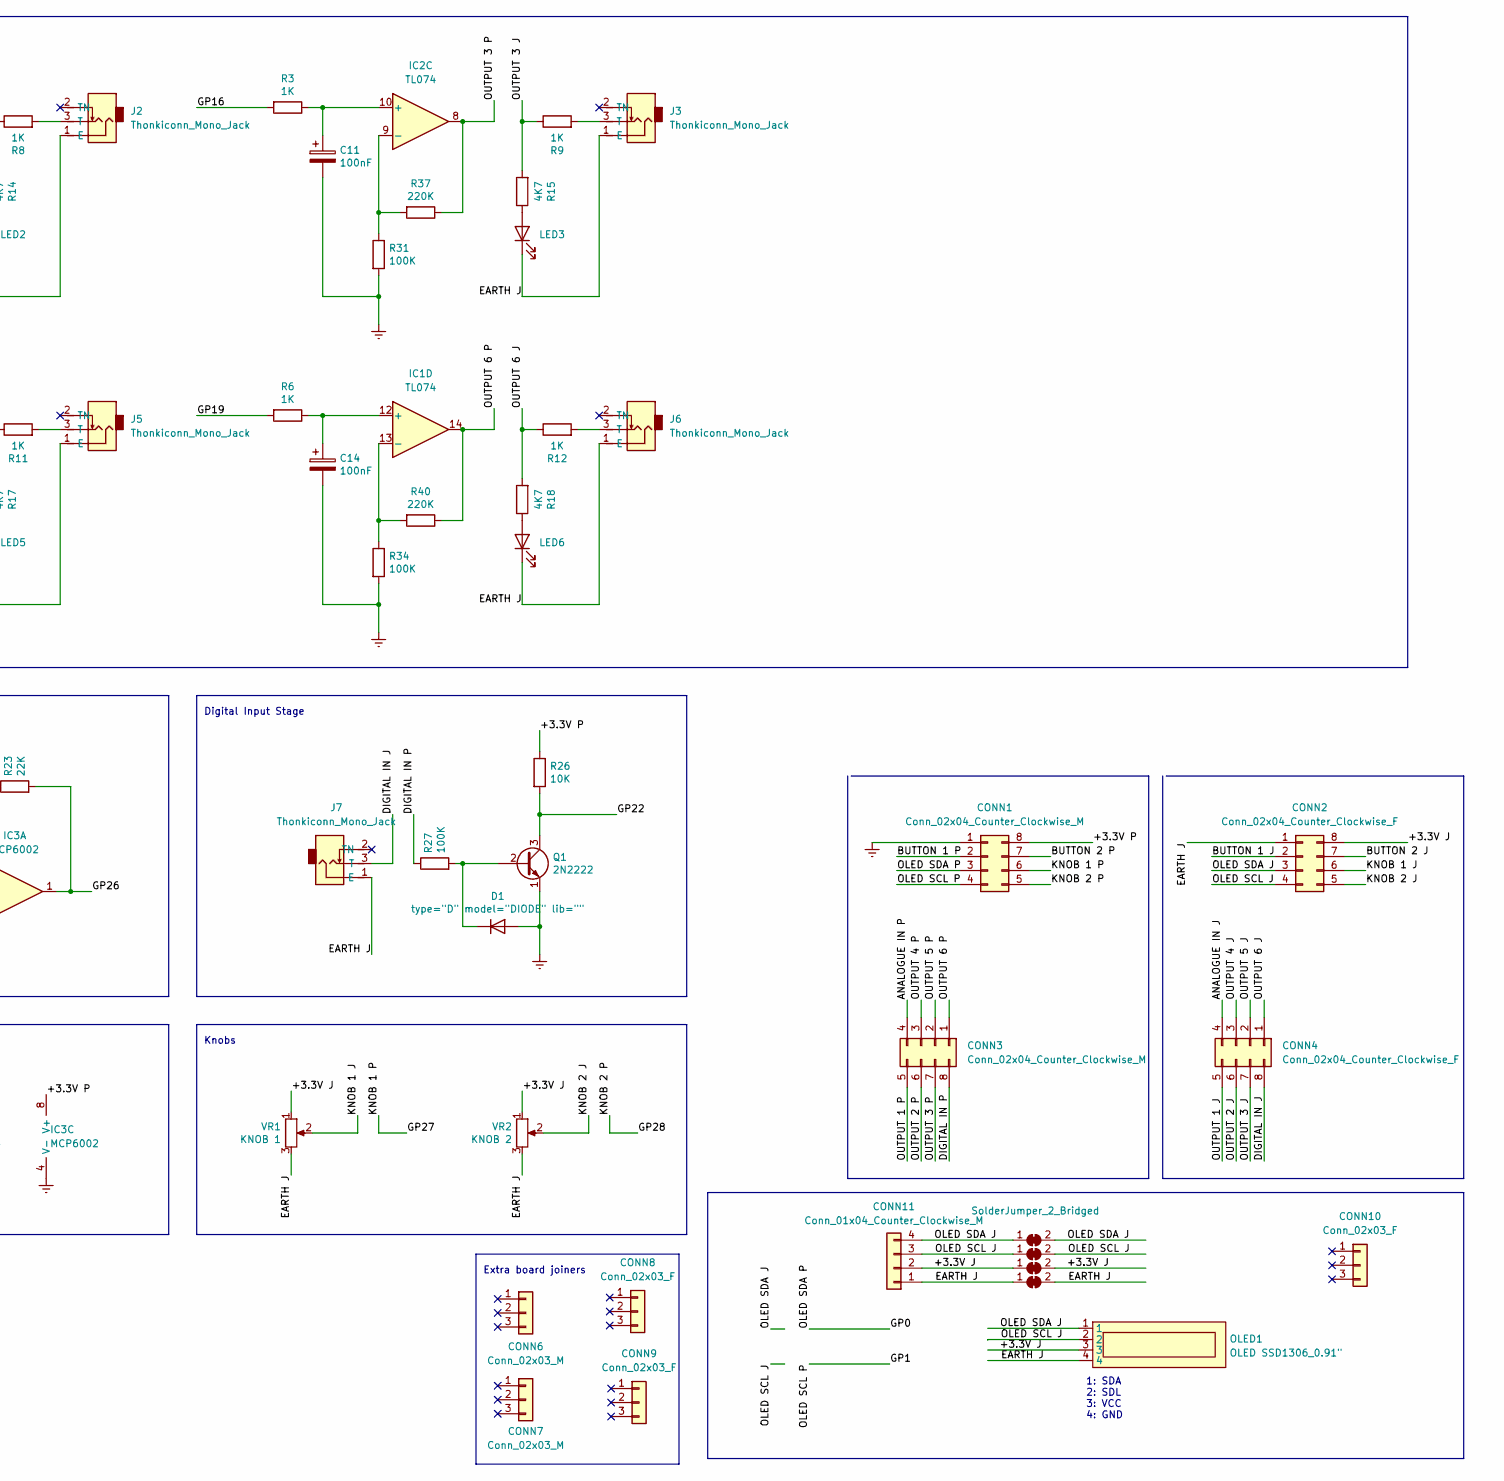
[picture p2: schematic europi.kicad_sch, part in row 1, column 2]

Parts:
C1, C2: 1uF; CP_Radial_D5.0mm_P2.50mm
C3, C4, C5, C6, C7, C8, C9, C10, C11, C12, C13, C14: 100nF; Capacitor Small Non-Polarised
C15, C16: 10uF; CP_Radial_D8.0mm_P3.80mm
CONN1, CONN3: Conn_02x04_Counter_Clockwise_M; PinHeader_2x04_P2.54mm_Vertical
CONN2, CONN4: Conn_02x04_Counter_Clockwise_F; PinSocket_2x04_P2.54mm_Vertical
CONN5: Conn_01x04_Male; PinHeader_1x04_P2.54mm_Vertical
CONN6, CONN7: Conn_02x03_M; PinHeader_1x03_P2.54mm_Vertical
CONN8, CONN9, CONN10: Conn_02x03_F; PinSocket_1x03_P2.54mm_Vertical
CONN11: Conn_01x04_Counter_Clockwise_M; PinHeader_1x04_P2.54mm_Vertical
D1, D2, D3, D4: type="D" model="DIODE" lib=""; Schottky Diode
EuroPower1: Eurorack Power; Eurorack Power Header Unlabeled
IC1, IC2: TL074; DIP-14 IC Socket
IC3: MCP6002; DIP-8 IC Socket
J1, J2, J3, J4, J5, J6, J7, J8: Thonkiconn_Mono_Jack; Thonkiconn Mono Jack
JP1, JP2, JP3, JP4: SolderJumper_2_Bridged; SolderJumper-2_P1.3mm_Bridged_Pad1.0x1.5mm
LED1, LED2, LED3, LED4, LED5, LED6: LED; LED 3mm
OLED1: OLED SSD1306_0.91"; OLED SSD1306 0.91-38mm
Q1: 2N2222; TO-92
R1, R2, R3, R4, R5, R6, R7, R8, R9, R10, R11, R12, R19, R20: 1K; R_Axial_DIN0204_L3.6mm_D1.6mm_P7.62mm_Horizontal
R13, R14, R15, R16, R17, R18: 4K7; R_Axial_DIN0204_L3.6mm_D1.6mm_P7.62mm_Horizontal
R21, R22, R23: 22K; R_Axial_DIN0204_L3.6mm_D1.6mm_P7.62mm_Horizontal
R24, R25, R26: 10K; R_Axial_DIN0204_L3.6mm_D1.6mm_P7.62mm_Horizontal
R27, R28, R29, R30, R31, R32, R33, R34: 100K; R_Axial_DIN0204_L3.6mm_D1.6mm_P7.62mm_Horizontal
R35, R36, R37, R38, R39, R40: 220K; R_Axial_DIN0204_L3.6mm_D1.6mm_P7.62mm_Horizontal
REG1: L7805; TO-220-3_Vertical
RPI1: Raspberry_Pi_Pico; Raspberry Pi Pico
SW1, SW2: SW_Push; SW_PUSH_6mm
VR1: KNOB 1; Potentiometer_RV09
VR2: KNOB 2; Potentiometer_RV09

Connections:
/+3.3V J: CONN2.8, CONN11.2, JP3.1 (A), JP3.2 (B), OLED1.3, VR1.1, VR2.1
/+3.3V P: C1.1, CONN1.8, CONN5.3, IC3.8 (V+), R24.2, R25.2, R26.1, RPI1.36 (3V3)
/+5V: C2.1, D2.1 (A), REG1.3 (OUT)
/+12V: C3.1, C5.1, C15.1, D4.2 (K), IC1.4 (V+), IC2.4 (V+), REG1.1 (IN)
/-12V: C4.2, C6.2, C16.2, D3.1 (A), IC1.11 (V-), IC2.11 (V-)
/ANALOGUE IN J: CONN4.4, J8.3 (T)
/ANALOGUE IN P: CONN3.4, R28.1
/BUTTON 1 J: C8.1, CONN2.2, R20.1
/BUTTON 1 P: CONN1.2, R24.1, RPI1.6 (GPIO4)
/BUTTON 2 J: C7.1, CONN2.7, R19.1
/BUTTON 2 P: CONN1.7, R25.1, RPI1.7 (GPIO5)
/DIGITAL IN J: CONN4.8, J7.3 (T)
/DIGITAL IN P: CONN3.8, R27.1
/GP0: CONN1.3, RPI1.1 (GPIO0)
/GP1: CONN1.4, RPI1.2 (GPIO1)
/GP2: CONN5.1, RPI1.4 (GPIO2)
/GP3: CONN5.2, RPI1.5 (GPIO3)
/GP6: RPI1.9 (GPIO6)
/GP7: RPI1.10 (GPIO7)
/GP8: RPI1.11 (GPIO8)
/GP9: RPI1.12 (GPIO9)
/GP10: RPI1.14 (GPIO10)
/GP11: RPI1.15 (GPIO11)
/GP12: RPI1.16 (GPIO12)
/GP13: RPI1.17 (GPIO13)
/GP14: RPI1.19 (GPIO14)
/GP15: RPI1.20 (GPIO15)
/GP16: R3.2, RPI1.21 (GPIO16)
/GP17: R4.2, RPI1.22 (GPIO17)
/GP18: R5.2, RPI1.24 (GPIO18)
/GP19: R6.2, RPI1.25 (GPIO19)
/GP20: R2.2, RPI1.26 (GPIO20)
/GP21: R1.2, RPI1.27 (GPIO21)
/GP22: Q1.3 (C), R26.2, RPI1.29 (GPIO22)
/GP26: IC3.1, R23.2, RPI1.31 (GPIO26_ADC0)
/GP27: CONN1.6, RPI1.32 (GPIO27_ADC1)
/GP28: CONN1.5, RPI1.34 (GPIO28_ADC2)
/KNOB 1 J: CONN2.6, VR1.2
/KNOB 2 J: CONN2.5, VR2.2
/OLED SCL J: CONN2.4, CONN11.3, JP2.1 (A), JP2.2 (B), OLED1.2
/OLED SDA J: CONN2.3, CONN11.4, JP1.1 (A), JP1.2 (B), OLED1.1
/OUTPUT 1 J: CONN4.5, R7.1, R13.2
/OUTPUT 1 P: CONN3.5, IC2.1, R35.1
/OUTPUT 2 J: CONN4.6, R8.1, R14.2
/OUTPUT 2 P: CONN3.6, IC2.7, R36.1
/OUTPUT 3 J: CONN4.7, R9.1, R15.2
/OUTPUT 3 P: CONN3.7, IC2.8, R37.1
/OUTPUT 4 J: CONN4.3, R10.1, R16.2
/OUTPUT 4 P: CONN3.3, IC2.14, R38.1
/OUTPUT 5 J: CONN4.2, R11.1, R17.2
/OUTPUT 5 P: CONN3.2, IC1.8, R39.1
/OUTPUT 6 J: CONN4.1, R12.1, R18.2
/OUTPUT 6 P: CONN3.1, IC1.14, R40.1
Earth: C1.2, C2.2, C3.2, C4.1, C5.2, C6.1, C7.2, C8.2, C9.2, C10.2, C11.2, C12.2, C13.2, C14.2, C15.2, C16.1, CONN1.1, CONN2.1, CONN5.4, CONN11.1, D1.1 (A), EuroPower1.3, EuroPower1.4, EuroPower1.5, EuroPower1.6, EuroPower1.7, EuroPower1.8, IC1.5 (+), IC3.3 (+), IC3.4 (V-), J1.1 (E), J2.1 (E), J3.1 (E), J4.1 (E), J5.1 (E), J6.1 (E), J7.1 (E), J8.1 (E), JP4.1 (A), JP4.2 (B), LED1.1 (K), LED2.1 (K), LED3.1 (K), LED4.1 (K), LED5.1 (K), LED6.1 (K), OLED1.4, Q1.1 (E), R29.2, R30.2, R31.2, R32.2, R33.2, R34.2, REG1.2 (GND), RPI1.3 (GND), RPI1.8 (GND), RPI1.13 (GND), RPI1.18 (GND), RPI1.23 (GND), RPI1.28 (GND), RPI1.33 (AGND), RPI1.38 (GND), SW1.1, SW2.1, VR1.3, VR2.3
unnamed: D1.2 (K), Q1.2 (B), R27.2
unnamed: D2.2 (K), RPI1.39 (VSYS)
unnamed: D3.2 (K), EuroPower1.1, EuroPower1.2
unnamed: D4.1 (A), EuroPower1.9, EuroPower1.10
unnamed: IC1.7, R21.2, R22.1
unnamed: IC1.6 (-), R21.1, R28.2
unnamed: C13.1, IC1.10 (+), R5.1
unnamed: IC1.9 (-), R33.1, R39.2
unnamed: C14.1, IC1.12 (+), R6.1
unnamed: IC1.13 (-), R34.1, R40.2
unnamed: C9.1, IC2.3 (+), R1.1
unnamed: IC2.2 (-), R29.1, R35.2
unnamed: C10.1, IC2.5 (+), R2.1
unnamed: IC2.6 (-), R30.1, R36.2
unnamed: C11.1, IC2.10 (+), R3.1
unnamed: IC2.9 (-), R31.1, R37.2
unnamed: C12.1, IC2.12 (+), R4.1
unnamed: IC2.13 (-), R32.1, R38.2
unnamed: IC3.2 (-), R22.2, R23.1
unnamed: J1.3 (T), R7.2
unnamed: J2.3 (T), R8.2
unnamed: J3.3 (T), R9.2
unnamed: J4.3 (T), R10.2
unnamed: J5.3 (T), R11.2
unnamed: J6.3 (T), R12.2
unnamed: LED1.2 (A), R13.1
unnamed: LED2.2 (A), R14.1
unnamed: LED3.2 (A), R15.1
unnamed: LED4.2 (A), R16.1
unnamed: LED5.2 (A), R17.1
unnamed: LED6.2 (A), R18.1
unnamed: R19.2, SW2.2
unnamed: R20.2, SW1.2

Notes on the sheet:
Buttons
5V Rail Regulation
Analogue Input Stage ALL CREDITS TO ÉMILIE GILLET mutable-instruments.net
Power Rail Filtering
Eurorack Power Connector
I2C Connector
Digital Input Stage
Extra board joiners
Raspberry Pi Pico
Output Stage(s)
1: SDA 2: SDL 3: VCC 4: GND
Knobs

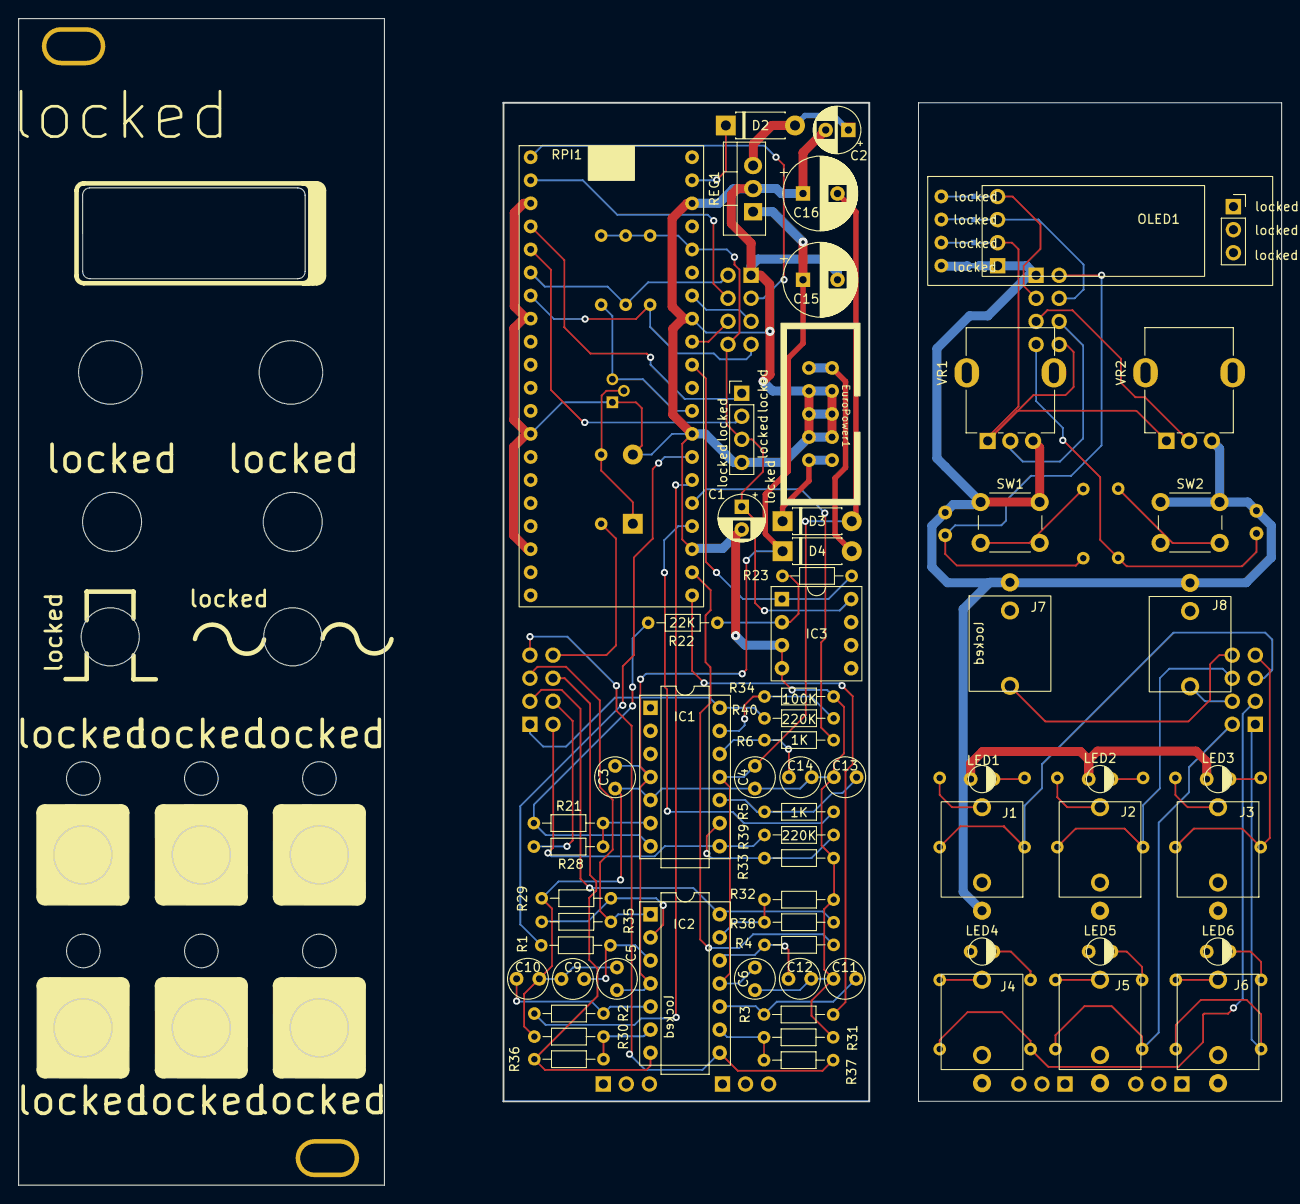
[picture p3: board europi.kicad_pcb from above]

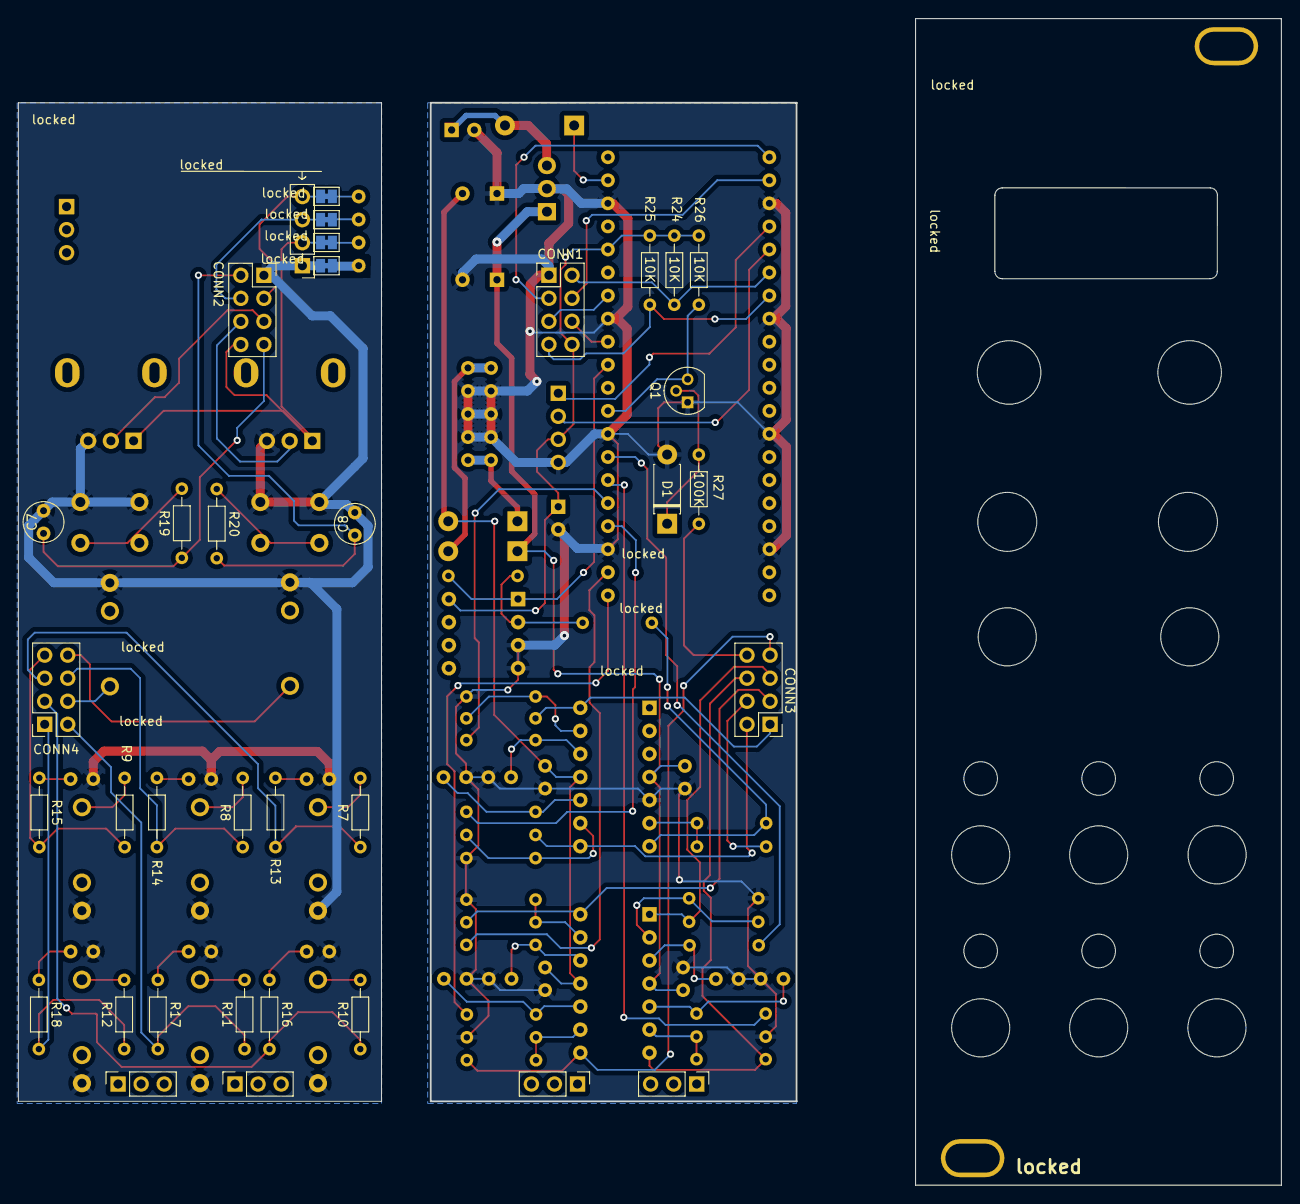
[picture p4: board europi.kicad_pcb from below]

Board: 2 copper layers, 139.1 x 128.5 mm, 109 parts (35 on the bottom side), 77 nets.

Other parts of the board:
3.7mm LED hole, 3.7mm LED hole#2, 3.7mm LED hole#3, 3.7mm LED hole#4, 3.7mm LED hole#5, 3.7mm LED hole#6: MountingHole_3.7mm
M3_MOUNT_BOTTOM, M3_MOUNT_TOP: MountingHole_M3

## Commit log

2023-10-22 KiCad redesign with all jacks on bottom, 38mm OLED
    [europi.kicad_pcb, europi.kicad_sch]
2023-10-22 Fix OLED window offset, add OLED I2C labels
    [europi.kicad_pcb]
2023-10-22 Remix v0.10.0-sss-tht production files
    [Black Panel - Bottom Copper (Paste).gbr, Black Panel - Bottom Copper (Resist).gbr, Black Panel - Bottom Copper.gbr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]
2023-10-22 Add OLED dimensions image to bom

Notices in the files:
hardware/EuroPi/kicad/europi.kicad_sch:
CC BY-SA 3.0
